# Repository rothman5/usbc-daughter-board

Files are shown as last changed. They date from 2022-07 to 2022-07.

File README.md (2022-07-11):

## Overview
This board uses [ai03's Unified Daughterboard](https://github.com/ai03-2725/Unified-Daughterboard) schematic design but with minor changes. The board is meant to be used in combination with my [Mech-Eighty](https://github.com/rothman5/mech-eighty) keyboard. It's purpose is to provide USB 2.0 full-speed operation circuitry on an external board. It integrates a USB Type C connector and the supporting components onto a small board. The assembly and design of the main keyboard is greatly simplified as a result.

## Features
- Overvoltage and ESD protection on USB voltage supply using a TVS diode.
- Overcurrent protection on USB current supply through a poly fuse.
- Achieves ESD protection on USB data lines using a specialized IC.
> Protection against ESD (electrostatic discharge) surges on the USB data lines is improved using the USBLC6-2SC6 integrated circuit. A single line TVS diode is used to protect the VBUS power line against ESD transients. These devices were chosen to comply with ST's application note ([AN4879](https://www.st.com/resource/en/application_note/an4879-usb-hardware-and-pcb-guidelines-using-stm32-mcus-stmicroelectronics.pdf)) recommendations.
- Noise decoupling with a ferrite bead.
> The ferrite bead inductor represents a low impedance path between the power and signal grounds. High frequency signals experience high impedance because of the bead. This protects against noisy signals passing to the signal ground.
- Shielding capabilities through single path grounding to a metallic case.
- See [ai03's Unified Daughterboard](https://github.com/ai03-2725/Unified-Daughterboard) for more technical information. 

## Photos
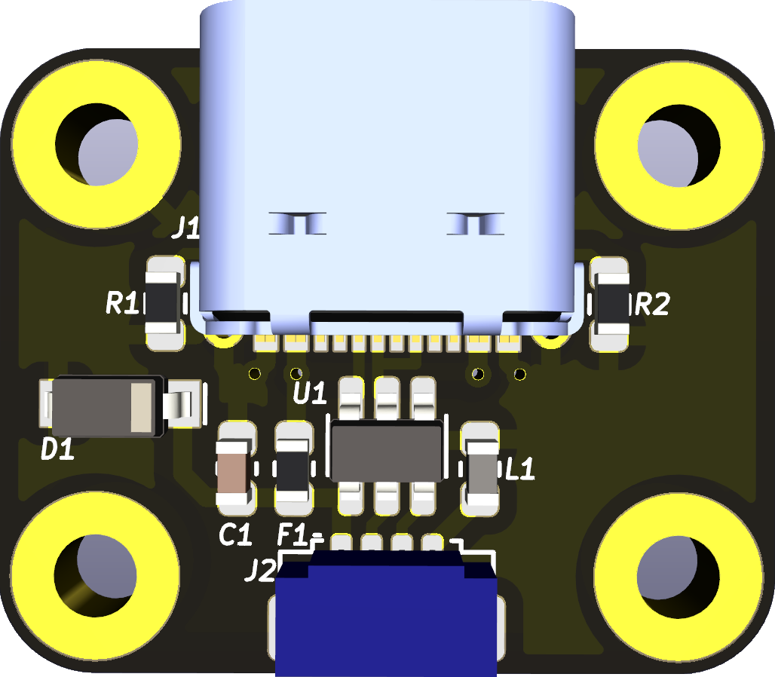
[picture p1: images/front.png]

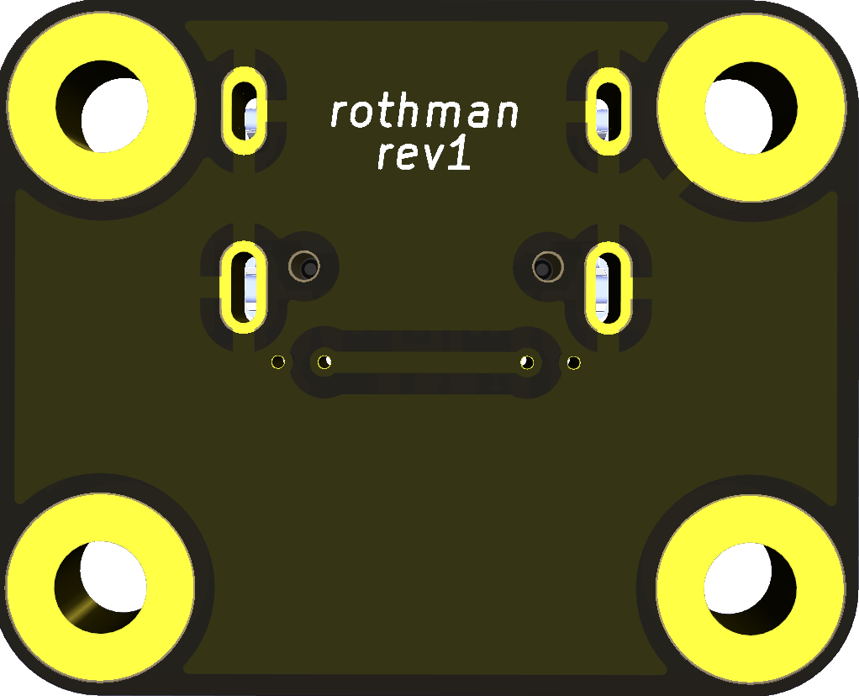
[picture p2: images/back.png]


## References
- ST USB power delivery application note ([TA0357](https://www.st.com/resource/en/technical_article/dm00496853-overview-of-usb-type-c-and-power-delivery-technologies-stmicroelectronics.pdf))
- ST USB hardware application note ([AN4879](https://www.st.com/resource/en/application_note/an4879-usb-hardware-and-pcb-guidelines-using-stm32-mcus-stmicroelectronics.pdf))
- ai03's [Unified Daughterboard](https://github.com/ai03-2725/Unified-Daughterboard)

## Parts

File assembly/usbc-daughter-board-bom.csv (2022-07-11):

Source: | D:\kicad-workspace\usbc-daughter-board\pcb\usbc-daughter-board.kicad_sch
Date: | 2022-07-11 9:58:13 AM
Tool: | Eeschema (6.0.5)
Generator: | D:\program-files\kicad\bin\scripting\plugins/bom_csv_grouped_by_value_with_fp.py
Component Count: | 13
Designator | Quantity | Value | Footprint | Manufacturer | Manufacturer Part # | Digikey Part #
C1, | 1 | 100n | Capacitor_SMD:C_0603_1608Metric | Samsung Electro-Mechanics | CL10B104KB8NNWC | 1276-1935-1-ND
D1, | 1 | D_TVS | Diode_SMD:D_SOD-123 | Comchip Technology | ATV02W5V0B-HF | 641-1986-1-ND
F1, | 1 | 500mA | Fuse:Fuse_0603_1608Metric | Littelfuse Inc. | 1206L050/15YR | F3733CT-ND
H1, H2, H3, H4, | 4 | M2 | MountingHole:MountingHole_2.2mm_M2_Pad
J1, | 1 | USB4105-GF-A | Connector_USB:USB_C_Receptacle_GCT_USB4105-GF-A
J2, | 1 | SM04B-SURS-TF | Connector_JST:JST_SUR_SM04B-SURS-TF_1x04-1MP_P0.80mm_Horizontal | JST Sales America Inc. | SM04B-SURS-TF(LF)(SN) | 455-3589-1-ND
L1, | 1 | 60R@100MHz | Inductor_SMD:L_0603_1608Metric | TDK Corporation | MAF1608GAD471LTAH0 | 445-181517-1-ND
R1, R2, | 2 | 5k1 | Resistor_SMD:R_0603_1608Metric | Stackpole Electronics Inc. | RMCF0603FT5K10 | RMCF0603FT5K10CT-ND
U1, | 1 | TPD4E001 | Package_TO_SOT_SMD:SOT-23-6 | Texas Instruments | TPD4E001QDBVRQ1 | 296-39344-1-ND

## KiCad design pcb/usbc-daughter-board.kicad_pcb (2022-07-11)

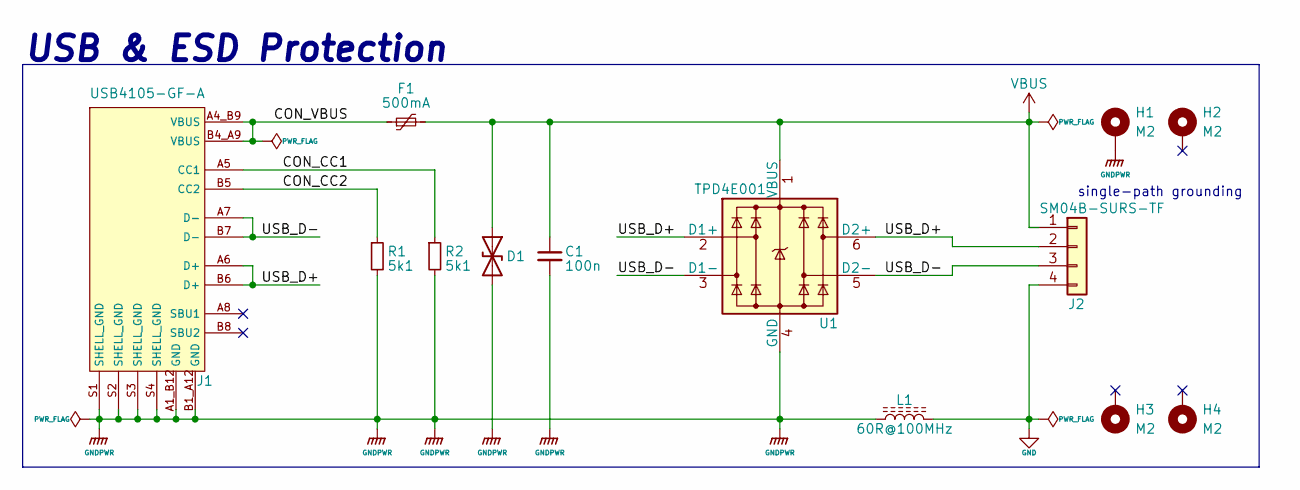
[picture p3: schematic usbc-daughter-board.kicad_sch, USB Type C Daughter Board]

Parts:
C1: 100n; C_0603_1608Metric; Manufacturer Part Number CC0603KRX7R9BB104; LCSC Part Number C14663
D1: D_TVS; D_SOD-123; Manufacturer Part # ATV02W5V0B-HF; Mouser Part # 750-ATV02W5V0B-HF
F1: 500mA; Fuse_0603_1608Metric; Manufacturer Part Number BSMD0603-050-6V; LCSC Part Number C883095
H1, H2, H3, H4: M2; MountingHole_2.2mm_M2_Pad
J1: USB4105-GF-A; USB_C_Receptacle_GCT_USB4105-GF-A
J2: SM04B-SURS-TF; JST_SUR_SM04B-SURS-TF_1x04-1MP_P0.80mm_Horizontal; Manufacturer Part # SM04B-SURS-TF(LF)(SN); Digikey Part # 455-3589-1-ND
L1: 60R@100MHz; L_0603_1608Metric; Manufacturer Part # MAF1608GAD471LTAH0; Mouser Part # 810-MAF1608GAD471LTA
R1, R2: 5k1; R_0603_1608Metric; Manufacturer Part Number 0603WAF5101T5E; LCSC Part Number C23186
U1: TPD4E001; SOT-23-6; Manufacturer Part # TPD4E001QDBVRQ1; Mouser Part # 595-TPD4E001QDBVRQ1

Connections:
/CON_CC1: J1.A5 (CC1), R2.1
/CON_CC2: J1.B5 (CC2), R1.1
/CON_VBUS: F1.1, J1.A4_B9 (VBUS), J1.B4_A9 (VBUS)
/USB_D+: J1.A6 (D+), J1.B6 (D+), J2.2, U1.2 (D1+), U1.6 (D2+)
/USB_D-: J1.A7 (D-), J1.B7 (D-), J2.3, U1.3 (D1-), U1.5 (D2-)
GND: J2.4, L1.2
GNDPWR: C1.2, D1.2 (A2), H1.1, J1.A1_B12 (GND), J1.B1_A12 (GND), J1.S1 (SHELL_GND), J1.S2 (SHELL_GND), J1.S3 (SHELL_GND), J1.S4 (SHELL_GND), L1.1, R1.2, R2.2, U1.4 (GND)
VBUS: C1.1, D1.1 (A1), F1.2, J2.1, U1.1 (VBUS)

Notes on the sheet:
single-path grounding
USB & ESD Protection

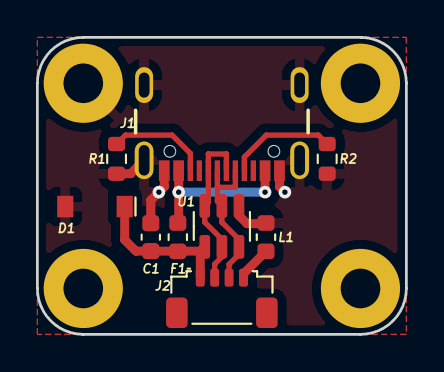
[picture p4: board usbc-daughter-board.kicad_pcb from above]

Board: 2 copper layers, 20.5 x 16.5 mm, 13 parts (0 on the bottom side), 8 nets.

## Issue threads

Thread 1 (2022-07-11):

Single-path grounding support

rothman5, 2022-07-11:
The daughter board currently doesn't support single-path grounding through the ferrite bead inductor.

rothman5, 2022-07-11:
Fixed #1in latest commit.

Closed 2022-07-11.

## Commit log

2022-07-03 Final product
    [usbc-daughter-board-B_Cu.gbr, usbc-daughter-board-B_Mask.gbr, usbc-daughter-board-B_Paste.gbr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]
2022-07-11 Added gerbers
    [usbc-daughter-board-B_Cu.gbl, usbc-daughter-board-B_Cu.gbr, usbc-daughter-board-B_Mask.gbr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]
